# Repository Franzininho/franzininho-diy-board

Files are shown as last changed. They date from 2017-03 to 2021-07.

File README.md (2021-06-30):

# Placa Franzininho DIY

Para mais detalhes sobre o projeto, montagem e programação, acesse a [documentação](https://franzininho.gitbook.io/franzininho-docs/)

O projeto é open hardware e foi publicado em [CC-BY-SA-4.0](https://github.com/Franzininho/franzininho-diy-board/blob/main/LICENSE)

A Franzininho DIY está certificada na [OSHWA com UID BR000003](https://certification.oshwa.org/br000003.html)

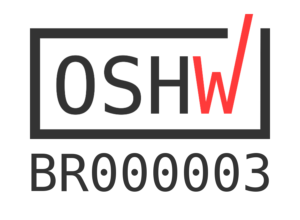
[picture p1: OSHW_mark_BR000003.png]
BR000003


Entenda mais sobre open hardware: [Open source hardware: Conheça a definição e as boas práticas](https://www.embarcados.com.br/open-hardware-definicao/)

# Características da Franzininho DIY

- Placa em face simples - Para facilitar a fabricação caseira;
- Componentes em PTH - Para montagem manual pois esse é um dos objetivos do projeto;
- Microcontrolador ATtiny85-20PU - Compatibilidade com Arduino
- 5 pinos I/O - Todos os pinos do microcontrolador disponíveis para o usuário
- LED de POWER - LED Verde para indicação da alimentação
- LED Amarelo de uso geral conectado a um pino de I/O D1
- Programação através da USB por Bootloader

# Projeto

O projeto da PCB foi desenvolvido originalmente no Eagle CAD. Para acompanhar o histórico do projeto acesse a [branch master](https://github.com/Franzininho/franzininho-diy-board/tree/master)

Todos as versões estão disponíveis nos [releases](https://github.com/Franzininho/franzininho-diy-board/releases)

A versão atual é a V2.2. Projeto no Kicad.

Para contribuições considerar a branch main. A branch master foi mantida apenas para histórico.

# Contribuição

## Sugestões e Bugs no hardware

Você dever reportar bugs ou sugestões através dá [área de Issues](https://github.com/Franzininho/franzininho-diy-board/issues) aqui no github.

Certifique-se de cumprir os seguintes critérios ao criar/enviar sua issue:

- Use um título claro e descritivo para identificar o problema/sugestão.
- Descreva as etapas exatas para reproduzir o problema em tantos detalhes quanto possível
- Mencione o local onde este problema foi encontrado e o que sua sugestão afetará

## Contribuição para melhorias no hardware

As contribuições da comunidade são sempre bem-vindas!

Esta seção destina-se a ajudar qualquer pessoa interessada em contribuir para este repositório.

Antes de contribuir, primeiro obtenha a aprovação dos mantenedores do repositório e da comunidade, levantando um problema do GitHub usando as diretrizes mencionadas na seção de sugestões.

Depois de obter aprovação, você precisará fazer os seguintes passos (estas instruções assumem que você é um usuário do GitHub).

- 1: fork esse repositório
- 2: Faça as alterações, commit e push para o fork
- 3: Envie o seu Pull Request

## Se tiver dúvidas entre em contato

contato@franzininho.com.br

## Siga as redes sociais e participe da comunidade

- [Site](https://franzininho.com.br/)
- [Facebook](https://goo.gl/1adfUv)
- [Instagram](https://goo.gl/PbgHqA)
- [Youtube](https://goo.gl/pJqHjC)
- [Comunidade no Facebook](https://goo.gl/fskViM)

## Exemplos de simulação no [Wokwi](https://wokwi.com/)

- [Franzininho Blink](https://wokwi.com/arduino/projects/301693553069785610)
- [Display de 7 segmentos e projeto de relógio](https://wokwi.com/arduino/projects/301738586036765194)
- [Exemplo de sensor analógico de temperatura](https://wokwi.com/arduino/projects/301751077214093834)
- [Projeto de sensor digital de umidade e temperatura](https://wokwi.com/arduino/projects/301745949656482317)
- [Projeto de controle servo motor](https://wokwi.com/arduino/projects/302291615188255242)
- [Projeto de contador de pulso externo](https://wokwi.com/arduino/projects/302199144424931848)

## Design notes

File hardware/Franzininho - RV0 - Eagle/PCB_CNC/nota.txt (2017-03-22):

#Versão para produção em CNC

As trilass são maiores e espaçamento entre elas está menor.

Não usar essa versão para outros métodos de produção

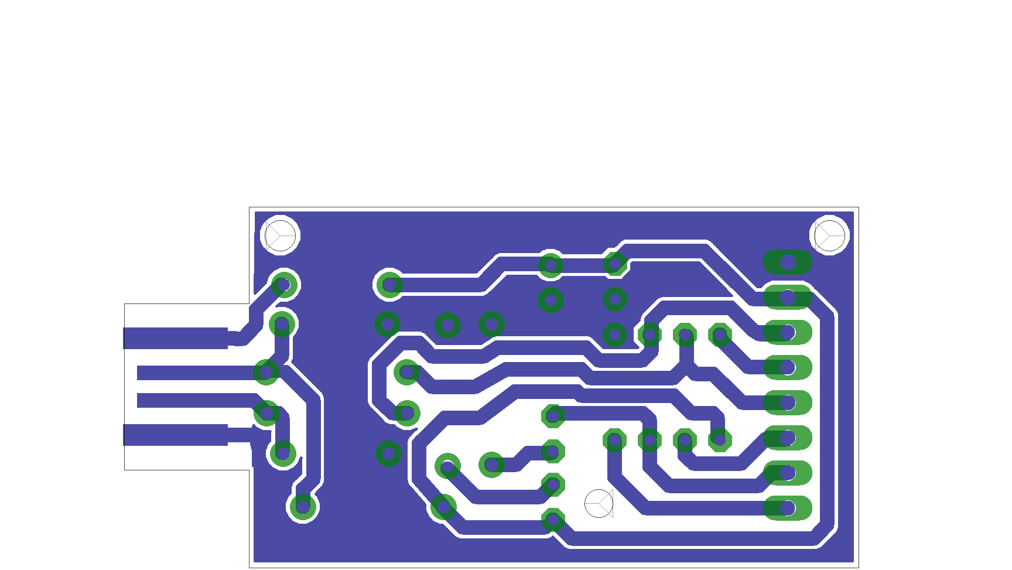
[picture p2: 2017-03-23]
hardware/Franzininho - RV0 - Eagle/PCB_CNC/trilhas.png

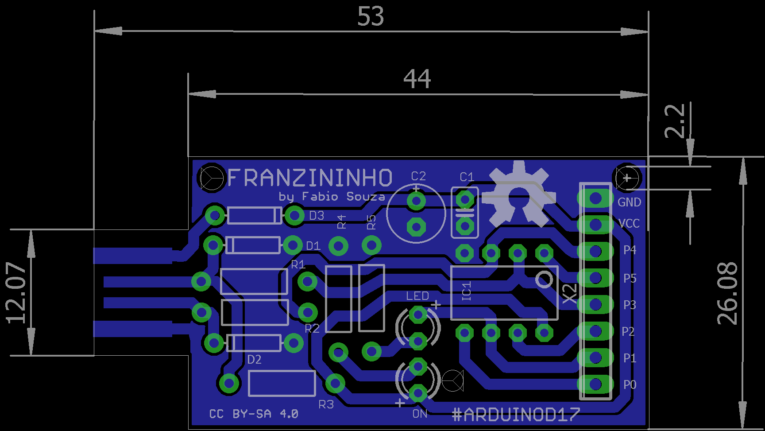
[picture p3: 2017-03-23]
hardware/Franzininho - RV0 - Eagle/PCB_CNC/imagem da placa com dimensões.png

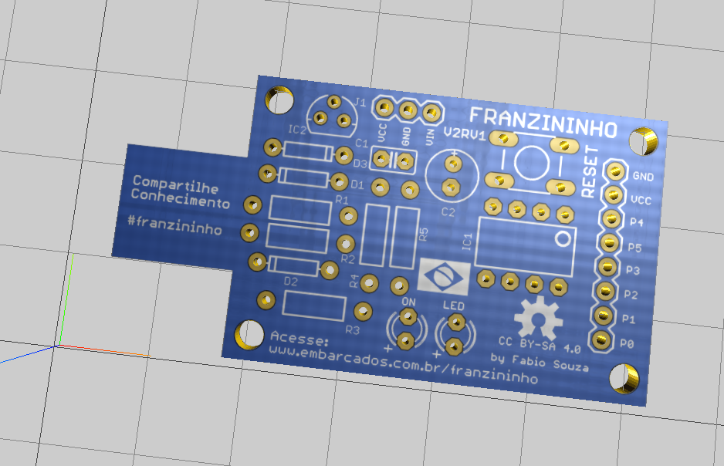
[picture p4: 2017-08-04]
hardware/Franzininho - RV2 - Eagle/3D.PNG

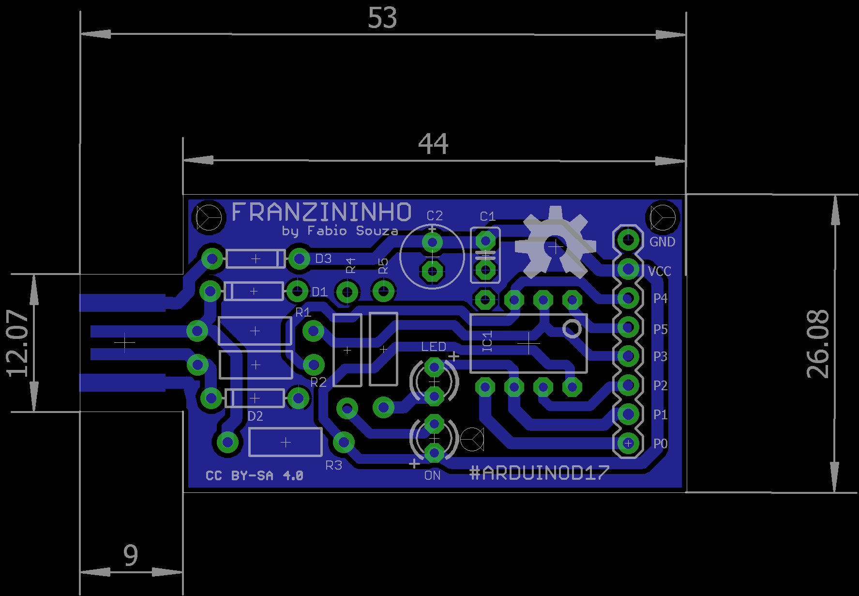
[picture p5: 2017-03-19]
hardware/Franzininho - RV0 - Eagle/Franzininho_brd.png

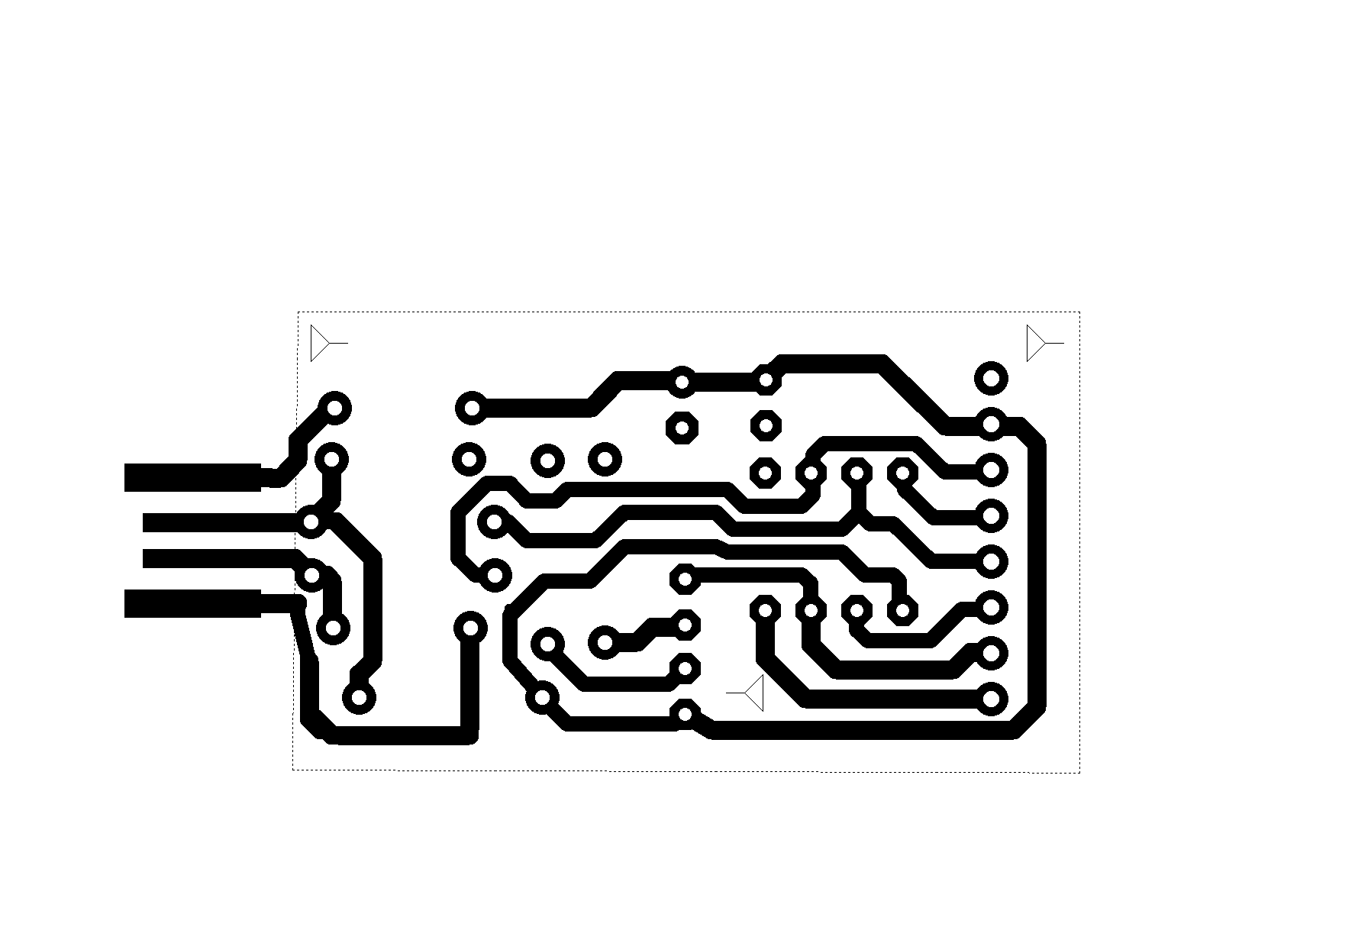
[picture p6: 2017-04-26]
hardware/Franzininho - RV0 - Eagle/trilhas_PNG.png

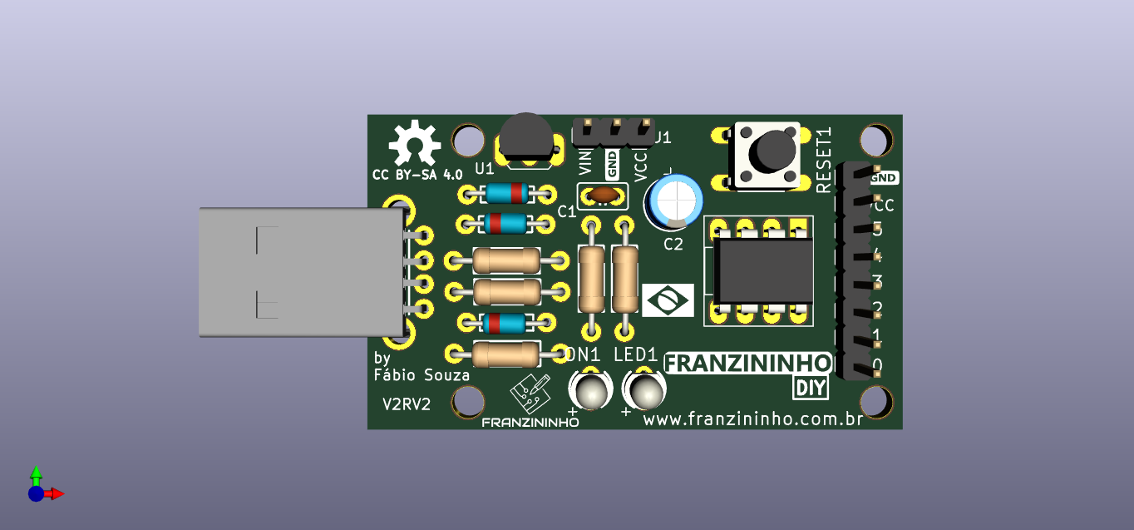
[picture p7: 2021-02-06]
Franzininho DIY/imagens/Franzininho-3D.png

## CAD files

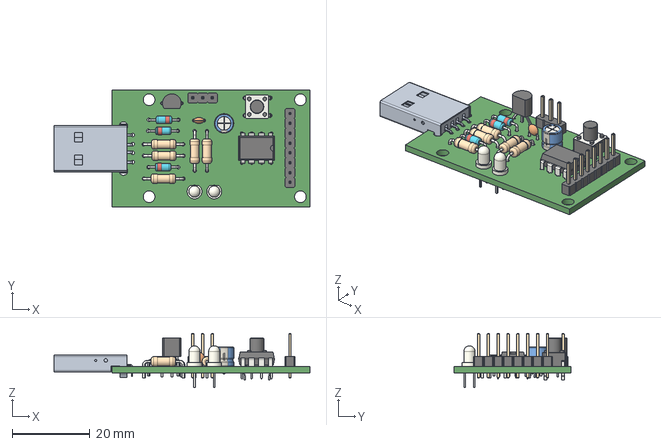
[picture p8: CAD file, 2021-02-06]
Franzininho DIY/Franzininho.step
66.0 x 30.0 x 14.0 mm

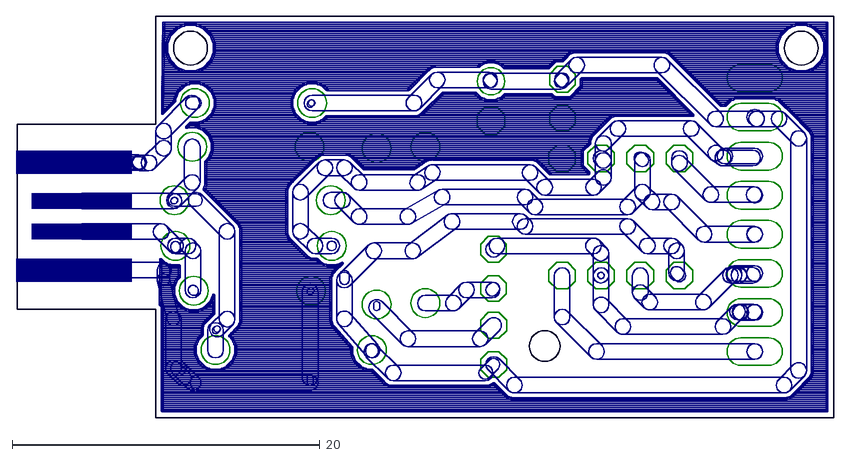
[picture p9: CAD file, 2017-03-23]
hardware/Franzininho - RV0 - Eagle/PCB_CNC/Franzininho_CNC.dxf
53.1 x 26.1

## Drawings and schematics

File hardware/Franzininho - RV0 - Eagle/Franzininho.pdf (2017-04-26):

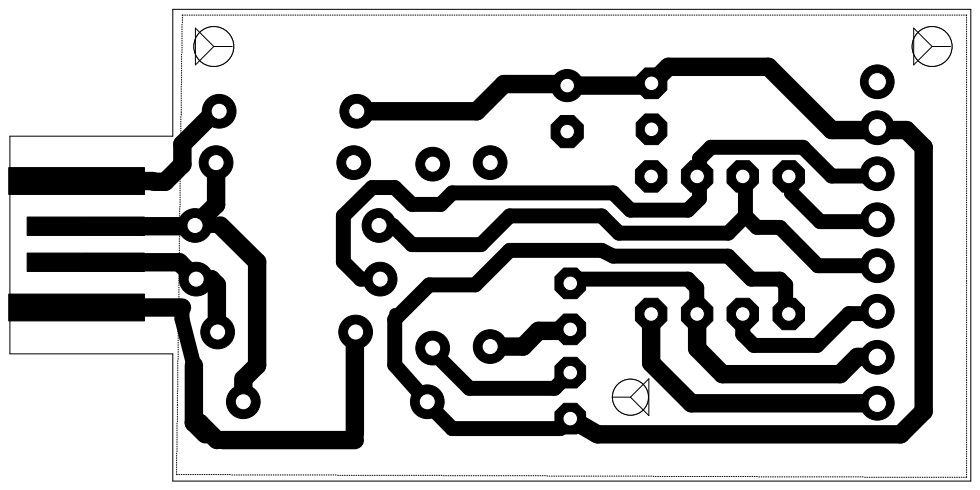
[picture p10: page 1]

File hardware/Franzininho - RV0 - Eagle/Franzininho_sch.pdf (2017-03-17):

A

A

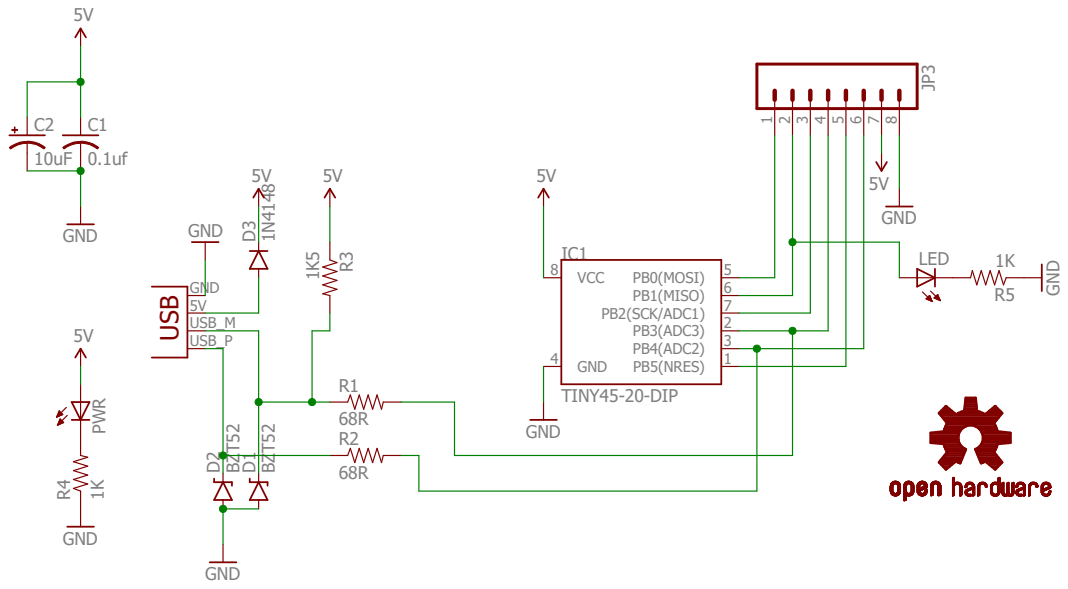
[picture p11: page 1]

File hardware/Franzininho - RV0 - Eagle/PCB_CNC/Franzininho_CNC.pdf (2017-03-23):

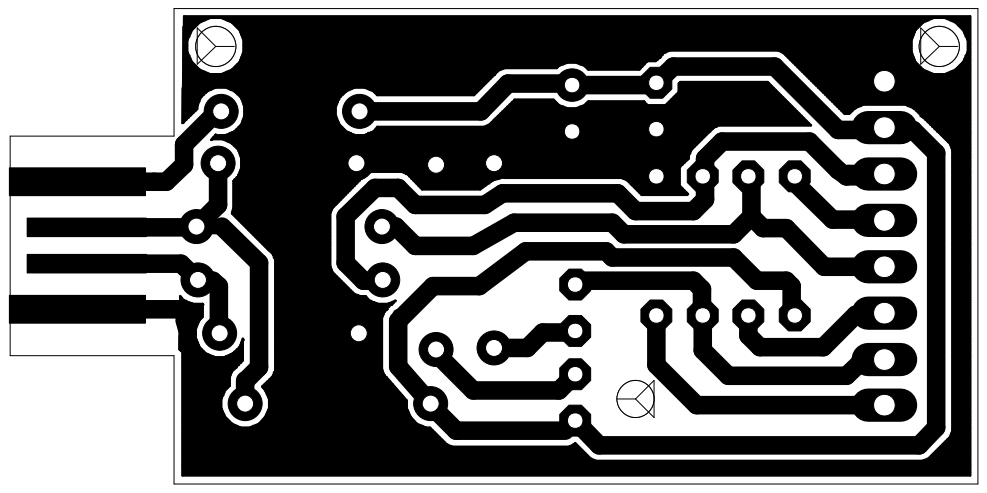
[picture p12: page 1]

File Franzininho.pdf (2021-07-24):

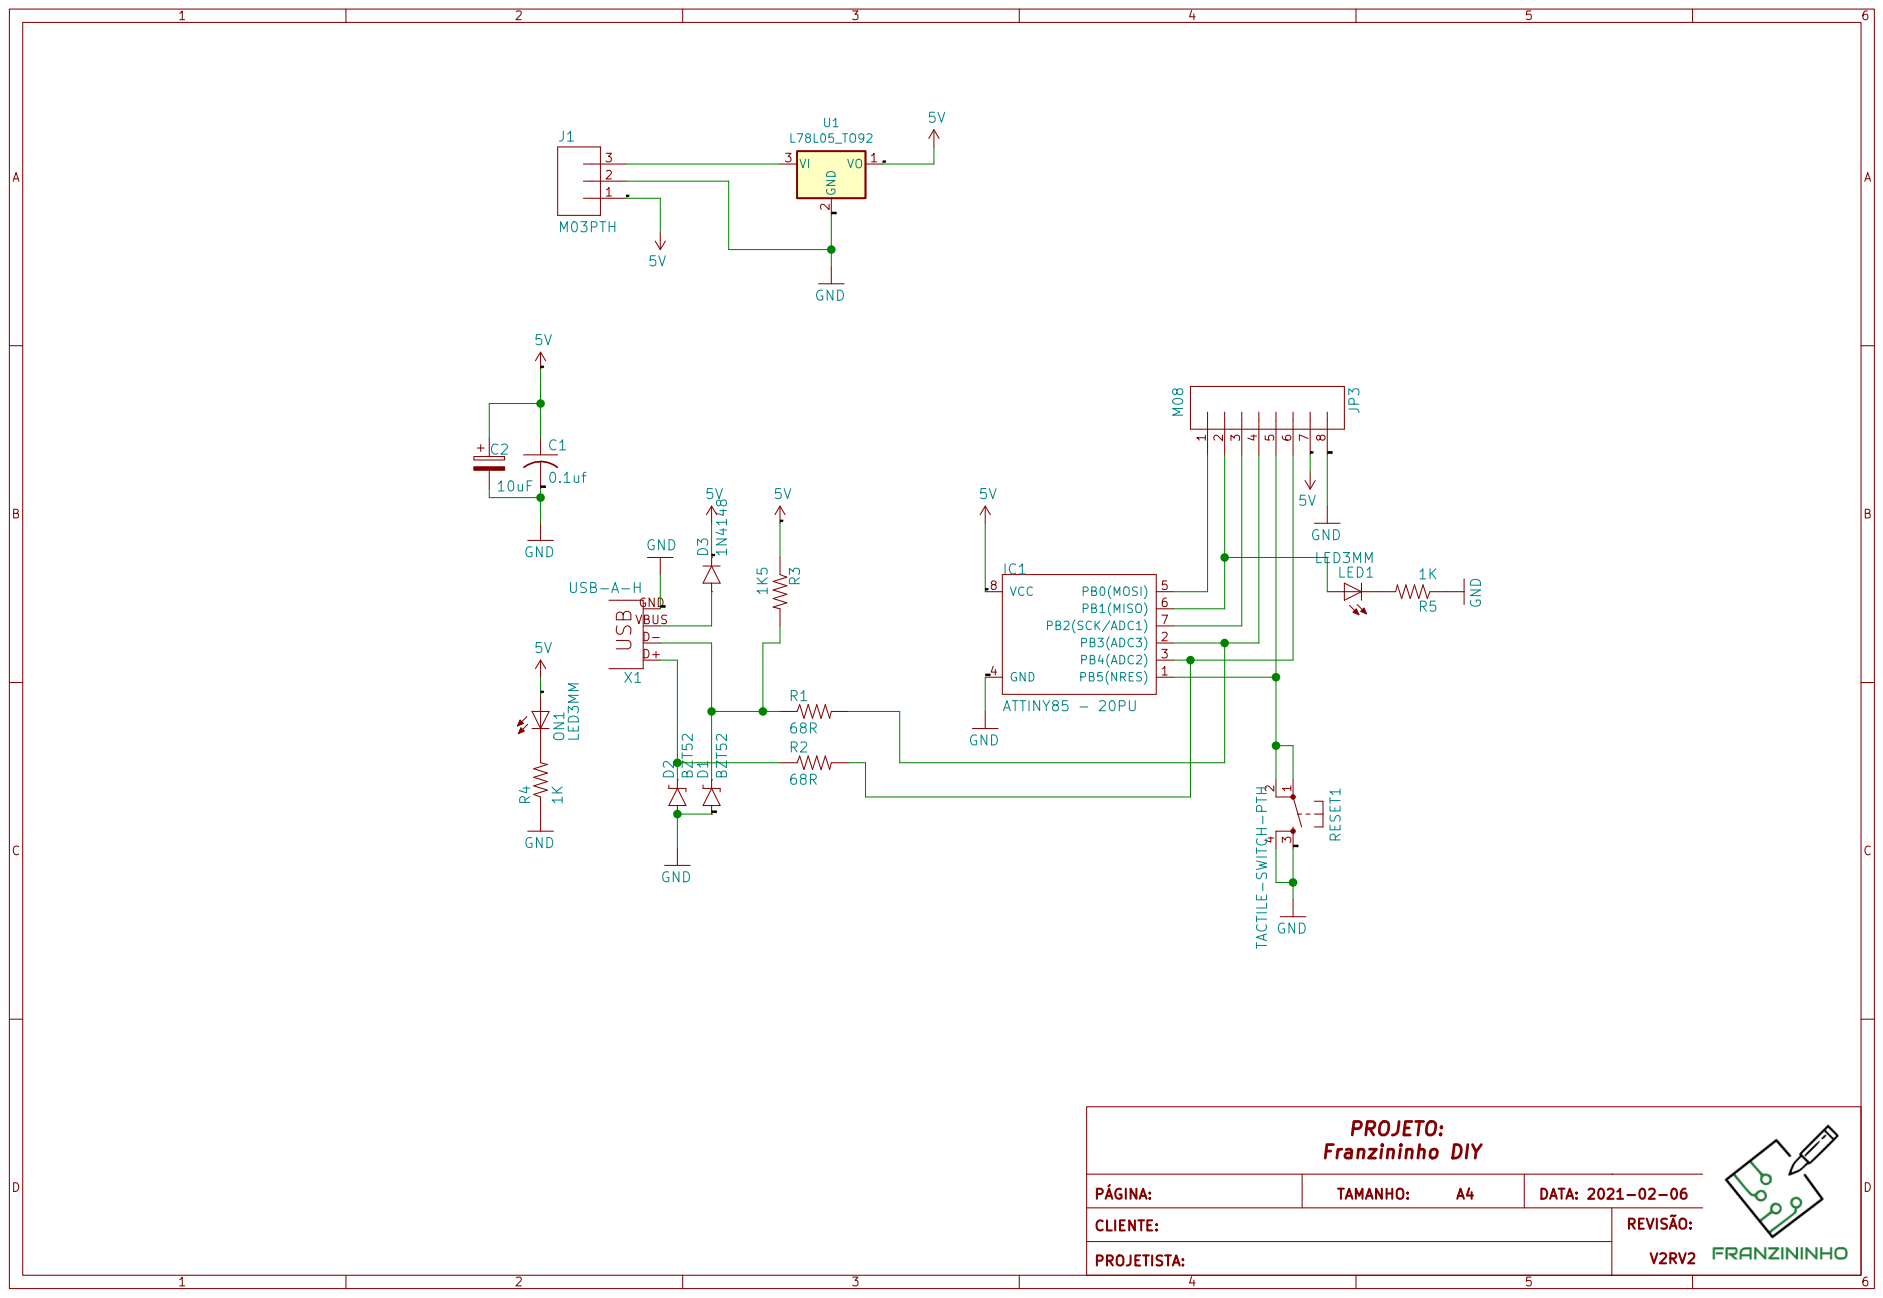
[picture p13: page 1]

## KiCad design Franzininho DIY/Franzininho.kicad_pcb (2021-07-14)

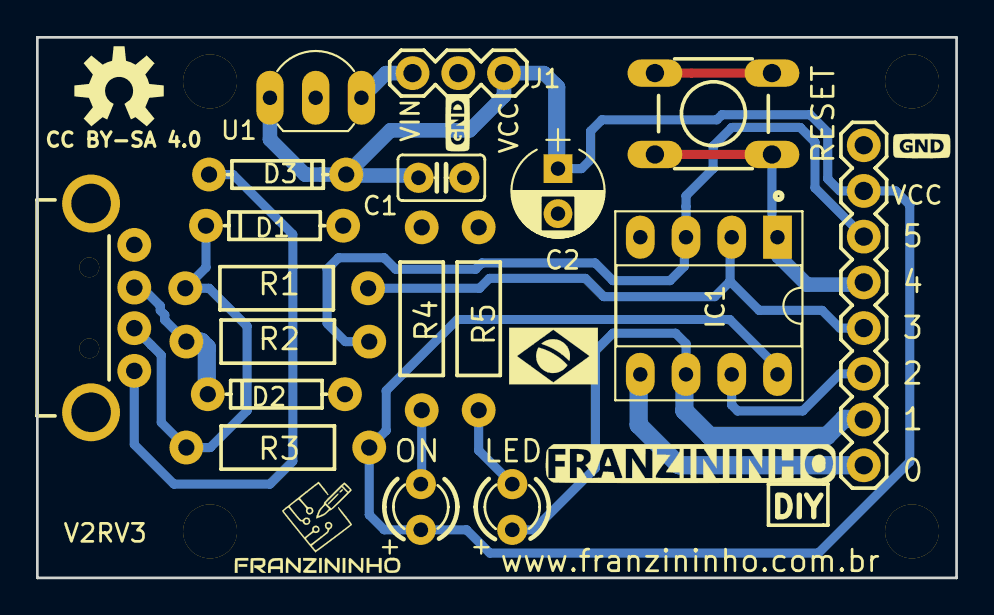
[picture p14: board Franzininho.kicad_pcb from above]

Board: 2 copper layers, 51.1 x 30.0 mm, 23 parts (0 on the bottom side), 14 nets.

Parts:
@HOLE0, @HOLE1, @HOLE2, @HOLE3: (no value)
C1: 0.1uf; C025-025X050
C2: 10uF; CP_Radial_D5.0mm_P2.50mm
D1, D2: BZT52; DIODE-BZT52
D3: 1N4148; DIODE-1N4148
IC1: ATTINY85 - 20PU; DIP-8_W7.62mm_Socket_LongPads
J1: M03PTH; 1X03
JP3: M08; 1X08_ROUND
LED: LED3MM
LOGO1: OSHW-LOGOM; OSHW-LOGO-M
ON: LED3MM
R1, R2: 68R; AXIAL-0.4
R3: 1K5; AXIAL-0.4
R4, R5: 1K; AXIAL-0.4
RESET: TACTILE-SWITCH-PTH; TAC-SWITCH-PTH
U1: L78L05_TO92; TO-92_Inline_Wide
X1: USB-A-H

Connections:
5V: C1.1, C2.1, D3.C, IC1.8, J1.1, JP3.7, ON.A, R3.P$1, U1.1
GND: C1.2, C2.2, D1.A, D2.A, IC1.4, J1.2, JP3.8, R4.P$1, R5.P$1, RESET.3, RESET.4, U1.2, X1.GND
unnamed: D1.C, R1.P$1, R3.P$2, X1.D-
unnamed: D2.C, R2.P$1, X1.D+
unnamed: D3.A, X1.VBUS
unnamed: IC1.1, JP3.5, RESET.1, RESET.2
unnamed: IC1.2, JP3.4, R1.P$2
unnamed: IC1.3, JP3.6, R2.P$2
unnamed: IC1.5, JP3.1
unnamed: IC1.6, JP3.2, LED.A
unnamed: IC1.7, JP3.3
unnamed: J1.3, U1.3
unnamed: LED.K, R5.P$2
unnamed: ON.K, R4.P$2

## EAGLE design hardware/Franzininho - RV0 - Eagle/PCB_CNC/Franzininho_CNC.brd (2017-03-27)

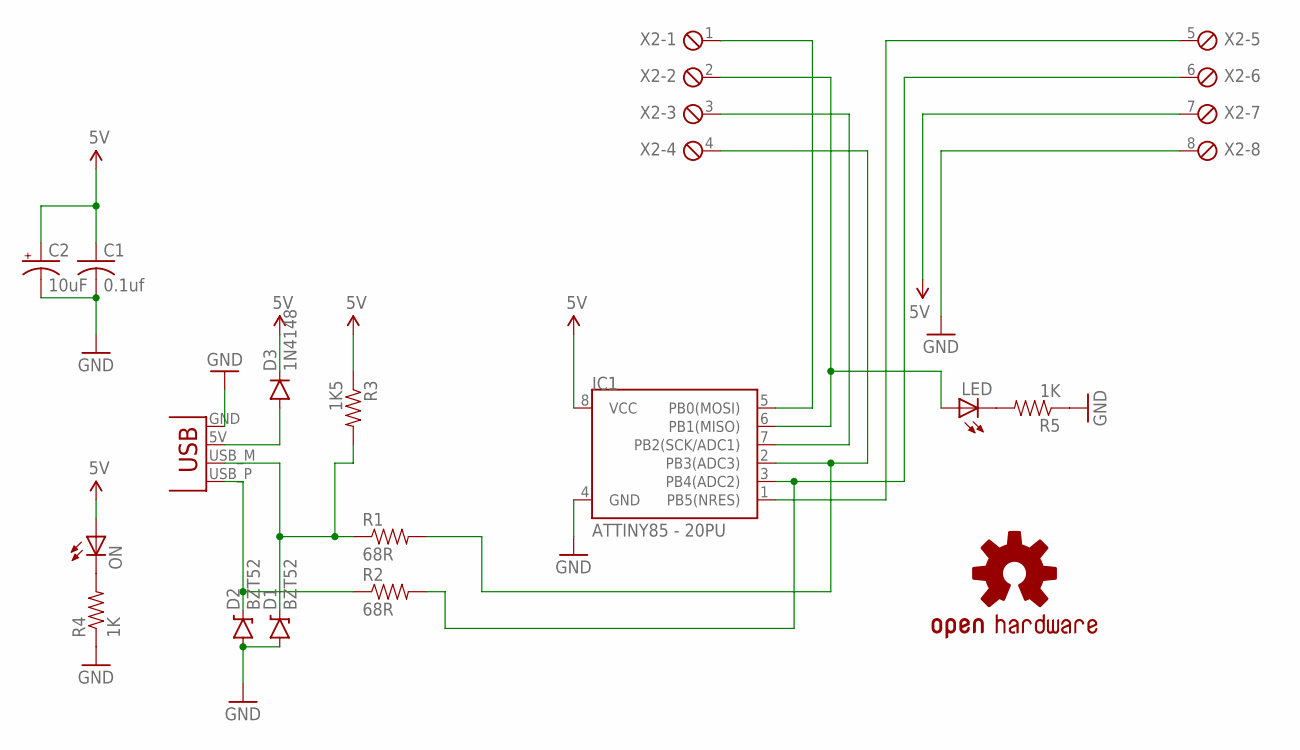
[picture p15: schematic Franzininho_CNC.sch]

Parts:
C1: 0.1uf; C025-025X050
C2: 10uF; E2,5-6E
D1, D2: BZT52; DIODE-BZT52
D3: 1N4148; DIODE-1N4148
IC1: ATTINY85 - 20PU; DIP08
LED: LED3MM
LOGO1: OSHW-LOGOL; OSHW-LOGO-L
ON: LED3MM
R1, R2: 68R; AXIAL-0.4
R3: 1K5; AXIAL-0.4
R4, R5: 1K; AXIAL-0.4
X1: USBPCB; USB-A-PCB
X2: MPT8; 8POL254

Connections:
5V: C1.1, C2.+, D3.C, IC1.8 (VCC), ON.A, R3.P$1 (1), X2.7
GND: C1.2, C2.-, D1.A, D2.A, IC1.4 (GND), R4.P$1 (1), R5.P$1 (1), X1.GND, X2.8
unnamed: IC1.2 (PB3(ADC3)), R1.P$2 (2), X2.4
unnamed: IC1.6 (PB1(MISO)), LED.A, X2.2
unnamed: IC1.5 (PB0(MOSI)), X2.1
unnamed: D3.A, X1.5V (VBUS)
unnamed: IC1.7 (PB2(SCK/ADC1)), X2.3
unnamed: IC1.3 (PB4(ADC2)), R2.P$2 (2), X2.6
unnamed: IC1.1 (PB5(NRES)), X2.5
unnamed: D1.C, R1.P$1 (1), R3.P$2 (2), X1.USB_M (D-)
unnamed: D2.C, R2.P$1 (1), X1.USB_P (D+)
unnamed: LED.K (C), R5.P$2 (2)
unnamed: ON.K (C), R4.P$2 (2)

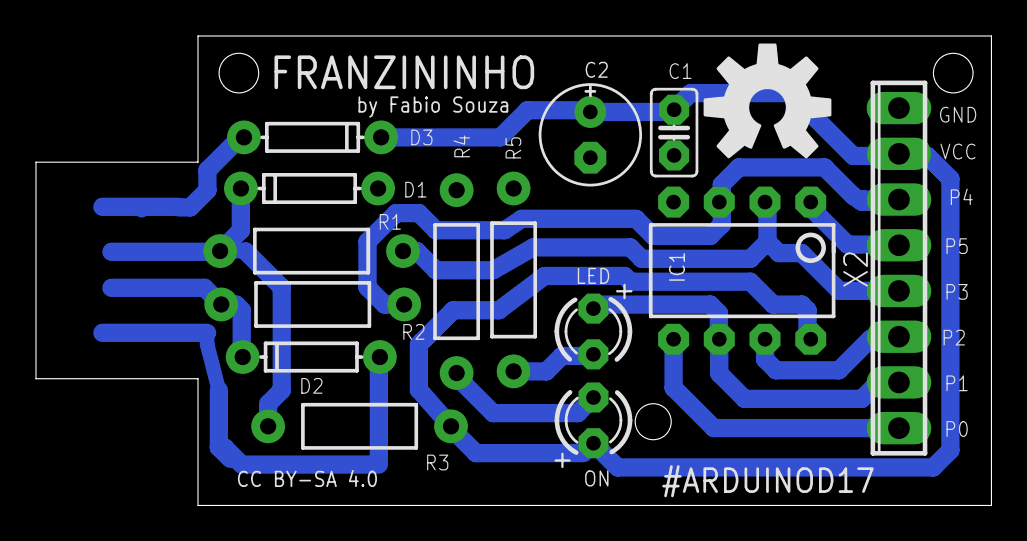
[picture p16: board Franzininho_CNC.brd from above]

Board: 2 copper layers, 53.1 x 26.1 mm, 16 parts (1 on the bottom side), 13 nets.

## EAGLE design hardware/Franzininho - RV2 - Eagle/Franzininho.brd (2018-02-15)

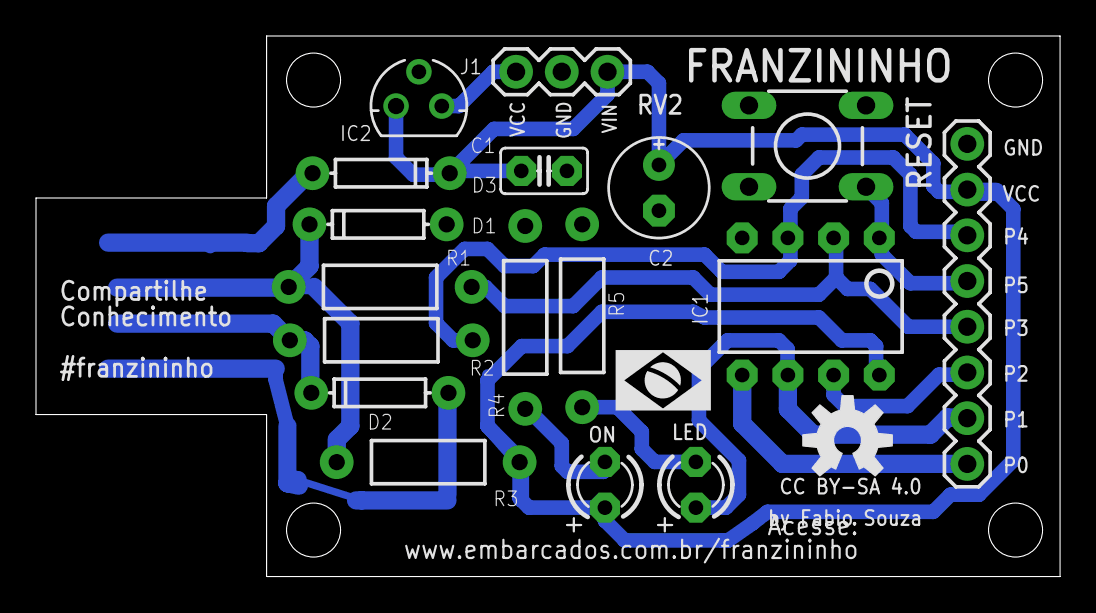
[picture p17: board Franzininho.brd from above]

Board: 2 copper layers, 56.9 x 30.0 mm, 19 parts (1 on the bottom side), 14 nets.

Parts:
C1: 0.1uf; C025-025X050
C2: 10uF; E2,5-6E
D1, D2: BZT52; DIODE-BZT52
D3: 1N4148; DIODE-1N4148
IC1: ATTINY85 - 20PU; DIP08
IC2: 78LXX
J1: 1X03
JP3: 1X08_ROUND
LED: LED3MM
LOGO1: OSHW-LOGOM; OSHW-LOGO-M
ON: LED3MM
R1, R2: 68R; AXIAL-0.4
R3: 1K5; AXIAL-0.4
R4, R5: 1K; AXIAL-0.4
RESET: TACTILE-SWITCH-PTH; TAC-SWITCH-PTH
X1: USBPCB; USB-A-PCB

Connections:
5V: C1.1, C2.+, D3.C, IC1.8, IC2.OUT, J1.1, JP3.7, ON.A, R3.P$1
GND: C1.2, C2.-, D1.A, D2.A, IC1.4, IC2.GND, J1.2, JP3.8, R4.P$1, R5.P$1, RESET.3, RESET.4, X1.GND
unnamed: IC1.2, JP3.4, R1.P$2
unnamed: IC1.6, JP3.2, LED.A
unnamed: IC1.5, JP3.1
unnamed: D3.A, X1.5V
unnamed: IC1.7, JP3.3
unnamed: IC1.3, JP3.6, R2.P$2
unnamed: IC2.IN, J1.3
unnamed: IC1.1, JP3.5, RESET.1, RESET.2
unnamed: D1.C, R1.P$1, R3.P$2, X1.USB_M
unnamed: D2.C, R2.P$1, X1.USB_P
unnamed: LED.K, R5.P$2
unnamed: ON.K, R4.P$2

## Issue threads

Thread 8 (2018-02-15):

Arquivos em PDF

aqmoreira, 2018-02-15:
Gerar os arquivos numa versão em PDF para quem não utiliza os software de CAD de PCB possam acesso as informações do esquema e placa.

FBSeletronica, 2018-02-15:
Olá Allan. Os arquivos foram colocados em PDF e também coloquei png da placa. Obrigado pela sugestão

Closed 2018-02-17.

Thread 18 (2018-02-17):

Erro ao gravar o código - avrdude: Error: Could not find USBtiny device (0x2341/0xc9f)

felipefernandes, 2018-02-17:
Instalei o driver e a IDE Arduino no Windows, escrevi o programa simplezinho (modificando  hello world), eu aperto o botão RESET antes de fazer o upload, a Franzininho troca o modo de piscar o led, mas ao invés de mudar modo de piscar (programa novo), eu recebo o erro **avrdude: Error: Could not find USBtiny device (0x2341/0xc9f)** na IDE do Arduino. Como posso resolver isso?

FBSeletronica, 2018-02-18:
Felipe, verifique no gerenciador de tarefas se a placa está sendo reconhecida pelo windows. Parece ser um erro de driver

Closed 2018-05-25.

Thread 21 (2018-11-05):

Compatibilidade Multiplataforma (Kicad Rev1)

franklinveras, 2018-11-05:
* O arquivo de projeto do kicad possui um **caminho absoluto** para as bibliotecas, impedindo que os arquivos de biblioteca de símbolos sejam encontrados em outros computadores de contribuidores do projeto.
* A **versão 2** do kicad, na qual o projeto foi feito, enumera as bibliotecas existentes no computador original no qual o arquivo foi feito, entretanto muitas dessas bibliotecas não tem relação com o projeto. A correção é feita de forma automática na versão 4, utilizando o arquivo de cache de bibliotecas.

Closed 2018-11-27.

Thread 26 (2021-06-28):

Novo recurso - Simulador grátis para Franzininho

matititam, 2021-06-28:
Olá

dia bom

temos um simulador online gratuito para placas Franzininho. O link está aqui: https://docs.wokwi.com/parts/wokwi-franzininho#simulator-examples

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

Teremos o maior prazer em compartilhar mais exemplos. Muitas pessoas já estão usando este simulador. Acredito fortemente que isso ajudará todos os seus leitores. Por favor, me diga se eu posso criar um PR para adicionar o link para o simulador Franzininho!
Obrigada!

FBSeletronica, 2021-06-28:
Opa. Estamos trabalhando junto ao wokwi para esse simulador. Fique a vontade para enviar o link em nossa documentação.

Muito obrigado

Closed 2021-07-14.

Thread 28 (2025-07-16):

BZT52 is a SMD-zener

Perdita-Olio, 2025-07-16:
Maybe a little late but I saw the PCB and the schematic diagram and I noticed in the schematic diagram the zeners are BZT52.
But they are SMD.
Which axial zener with the same properties I can use? A 1N4733A or a BZV85‑C5V1?
On Hackster.io these both zeners were mentioned as 3.6 volts, 0.5Watt.
Are these zeners working quite well?

Perdita-Olio, 2025-08-29:
@vinRocha
Thanks for your reply. I wil try it with the mentioned zener-diodes.
One more question: what's the difference between the PCB's V2RV1 and V2RV2?

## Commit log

2017-03-17 init
    Franzininho V0
    [Franzininho.brd, Franzininho.sch]
2017-03-17 init
    organização de pastas
    [Franzininho.brd, Franzininho.sch]
2017-03-17 update
    aumentado um pouco o tamanho da placa
    [Franzininho.brd]
2017-03-19 CNC
    para usinagem em CNC*:
    Trilhas maiores, espaçamento menor
    *Usar essa versão apenas para usinagem em CNC
    [Franzininho_CNC.brd, Franzininho_CNC.sch]
2017-03-19 layout
    Melhorias no Layout
    BOM
    Nova imagem da placa com melhor resolução e cotas
    [Franzininho.brd]
2017-03-23 Arquivos para preparação de produção em CNC
    [Franzininho_CNC.dxf]
2017-03-27 gebers para produção
2017-03-27 atualização de arquivos
    [Franzininho.brd, Franzininho.sch, Franzininho_CNC.brd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]
2017-04-04 updade de texto
2017-04-26 trilha para processo termico
2017-05-16 RV1
    Inserido botão de reset, furos, melhora no conector USB e aumentado um
    pouco as dimensões da placa.
    [Franzininho.brd, Franzininho.sch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]
2017-06-17 bt
    atualizado exemplo de BT
2017-07-06 imagens
    imagens para documentação
2017-07-10 add KiCAD version
    [franzininho-rev1.kicad_pcb, franzininho-rev1.sch]
2017-07-10 link para texto das oficinas
2017-08-04 V2
    Nova versão com regulador de tensão para alimentação externa
    [Franzininho.brd, Franzininho.sch]
2017-08-04 V3
    placa com conector USB
    [Franzininho.brd, Franzininho.sch]
2017-11-03 arquivos com trilhas na RV1
    Arquivos para fabricação caseira
    [Franzininho.brd]
2017-11-17 Tutorial Programação
    Primeiros passos para programação da Franzininho na IDE Arduino
2017-11-19 EmuladorTeclado
    Código para Emular teclado
2017-11-21 organizado as revisões
    [Franzininho.brd, Franzininho.sch, Franzininho_CNC.brd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]
2017-11-24 Fritzing part
    Componente para uso no Fritzing
2017-12-27 correção do conector USB
    [Franzininho.brd, Franzininho.sch]
2018-02-13 tutorial import Fritzing
    Tutorial para importar componente Franzininho para o Fritizing
2018-02-13 ajuste de cabeçalhos
2018-02-15 sch e brd em pdf
    adiconado arquivos em pdf para facilitar o acesso a quem não tem CAD
    [Franzininho.brd]
2018-02-20 Enviado para organização
    Enviado para repositório Fritzing na organização Franzininho
2018-05-25 Organização das pasta e versões
    [Franzininho.brd, Franzininho.sch, Franzininho_CNC.brd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]
2018-05-26 link para a licença
2018-08-20 imagem esquemático
    [Franzininho.brd, Franzininho.sch]
2018-11-05 Compatibilidade Multiplataforma (Kicad Rev1) - Issue #21
    [franzininho-rev1.sch]
2018-12-03 V2RV1
    Nova revisão da placa Franzininho V2. Foram feitos alguns ajustes no silk e footprints
    [Franzininho-B.Mask.gbs, Franzininho-B.Paste.gbp, Franzininho-B.SilkS.gbo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]
2019-08-29 V2RV1 kicad
    [Franzininho-DIY-LUCHTEC-B.Mask.gbs, Franzininho-DIY-LUCHTEC-B.Paste.gbp, Franzininho-DIY-LUCHTEC-B.SilkS.gbo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]
2019-08-29 V2RV2 - Corrigido GND no C2
    [Franzininho.kicad_pcb]
2019-08-29 V2RV2 - gerber
    [Franzininho-B.Paste.gbp, Franzininho-B_Mask.gbs, Franzininho-B_Paste.gbp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]
2020-11-27 Adiconando projeto Kicad da V2.2
    [Franzininho-B_Mask.gbs, Franzininho-B_Paste.gbp, Franzininho-B_SilkS.gbo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]
2020-11-27 Removendo RV0 da branch main
    [Franzininho.brd, Franzininho.sch, Franzininho_CNC.brd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]
2020-11-27 Removendo RV1 da branch main
    [Franzininho.brd, Franzininho.sch, franzininho-rev1.kicad_pcb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]
2020-11-27 Removendo RV2 - Eagle da branch main
    [Franzininho.brd, Franzininho.sch]
2020-11-27 Removendo V2 - Eagle da branch main
    [Franzininho.brd, Franzininho.sch]
2020-11-27 Removendo V2RV1 -Kicad da branch main
    [Franzininho-B_Mask.gbs, Franzininho-B_Paste.gbp, Franzininho-B_SilkS.gbo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]
2020-11-27 Removendo zip do gerber da v2rv1 da pasta
2020-11-27 Renomeando pasta do projeto Kicad para Franzininho DIY
    [Franzininho-B_Mask.gbs, Franzininho-B_Paste.gbp, Franzininho-B_SilkS.gbo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]
2020-11-27 Adiconando arquivos que não estavam sendo monitorados devido ao .gitignore
    [Franzininho-NPTH.drl, Franzininho-PTH.drl]
2020-11-27 Ajustando o README.md para melhor apresentação após a limpeza no repositório e colocando a branch main como default
2021-02-06 Ajustando lib 3D e gerando arquivo step
    [Franzininho.kicad_pcb, Franzininho.sch, Franzininho.step]
2021-02-06 Salvando arquivo de bkp
2021-06-30 Ajuste de texto
2021-07-14 Ajuste da área de cobre para de solid para thermal relief para facilitar a soldagem. Ajuste de silks. Adicionado um ponto para indicar o pino 1 do mcu. Refeito área de cobre com um clearece menor
    [Franzininho-B_Mask.gbs, Franzininho-B_Paste.gbp, Franzininho-B_SilkS.gbo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]

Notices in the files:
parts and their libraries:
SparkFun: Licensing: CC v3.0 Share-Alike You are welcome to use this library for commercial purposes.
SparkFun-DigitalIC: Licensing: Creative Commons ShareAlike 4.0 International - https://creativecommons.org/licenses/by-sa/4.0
